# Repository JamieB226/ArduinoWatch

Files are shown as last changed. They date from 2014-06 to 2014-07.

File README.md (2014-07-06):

ArduinoWatch
============

Code for ArduinoWatch<BR>

Android - Android App Project<BR>
Arduino - Code for the Arduino<BR>
Diagrams - Fritzing diagram of the connections in the project<BR>
Libraries - Libraries for the Arduino project (mine and modified from Adafruit)

Required components:<BR>
<BR>
Arduino Pro Mini - 3.3V 8MHz version - <A HREF="http://arduino.cc/en/Main/ArduinoBoardProMini">link</A><BR>
Adafruid Bluefruit LE breakout board (nRF8001 chipset) -  <A HREF="http://www.adafruit.com/products/1697">link</A><BR>
Monochrome 1.3" 128x64 OLED Display (SSD1306 controller) -  <A HREF="http://www.adafruit.com/products/938">link</A><BR>
USB LiIon/LiPoly charger - <A HREF="http://www.adafruit.com/products/259">link</A><BR>
FTDI Basic breakout (to upload code to Arduino - not required in final design) - <A HREF="https://www.sparkfun.com/products/9873">link</A><BR>
400 mAH Lithium Polymer battery - <A HREF="https://www.sparkfun.com/products/10718">link</A><BR>
Vibration Motor - <A HREF="http://www.adafruit.com/products/1201">link</A>

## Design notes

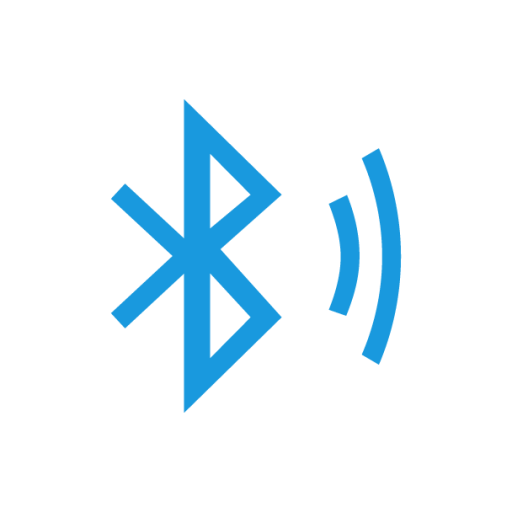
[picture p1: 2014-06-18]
Android/ic_launcher-web.png

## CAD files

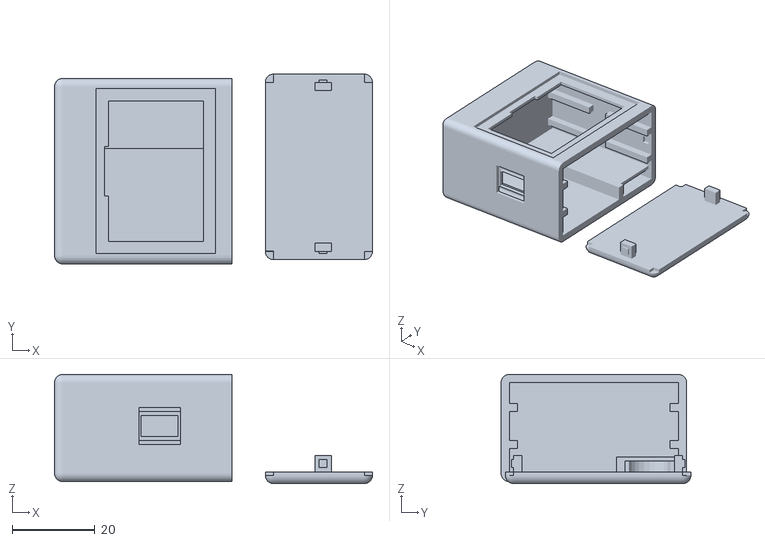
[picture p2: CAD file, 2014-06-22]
Diagrams/ArduinoWatch.stl
77.1 x 46.0 x 26.5

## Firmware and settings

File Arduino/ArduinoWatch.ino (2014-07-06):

#include <SPI.h>
#include "Adafruit_BLE_UART.h"
#include <Wire.h>
#include <avr/pgmspace.h>
#include "Time.h"

#define ADAFRUITBLE_REQ 5
#define ADAFRUITBLE_RDY 2     // This should be an interrupt pin, on Uno thats #2 or #3
#define ADAFRUITBLE_RST 9
Adafruit_BLE_UART BTLEserial = Adafruit_BLE_UART(ADAFRUITBLE_REQ, ADAFRUITBLE_RDY, ADAFRUITBLE_RST);
aci_evt_opcode_t laststatus;

// pin definitions
#define OLED_DATA 11
#define OLED_CLK 13
#define OLED_DC 6
#define OLED_CS 7
#define OLED_RST 8

#define VIBRATION 4
#define BATTSTAT1 A0
#define BATTSTAT2 A1

#include <SSD1306ASCII.h>
#define SSD1306_COLUMNADDR 0x21
#define SSD1306_PAGEADDR   0x22

uint8_t xpos=0,ypos=0;

static unsigned char __attribute__ ((progmem)) GMail_Logo[]={0xFF,0xFF,0x06,0x06,0x0C,0x0C,0x06,0x06,0xFF,0xFF};
static unsigned char __attribute__ ((progmem)) EMail_Logo[]={0xFF,0x83,0x85,0x89,0x91,0x91,0x89,0x85,0x83,0xFF};
static unsigned char __attribute__ ((progmem)) RSS_Logo[]={0xDB,0xDB,0x1B,0xF3,0xEE,0x0E,0xFC,0xF0};
static unsigned char __attribute__ ((progmem)) NestHome_Logo[]={0x00,0x3C,0x7E,0x81,0xE7,0xE7,0xE7,0x81,0x7E,0x3C};
static unsigned char __attribute__ ((progmem)) NestAway_Logo[]={0x00,0x3C,0x7E,0x83,0xED,0xED,0xED,0x83,0x7E,0x3C};
static unsigned char __attribute__ ((progmem)) Charged_Logo[]={0x18,0x38,0x70,0xE0,0x70,0x38,0x1C,0x0E,0x07,0x03};
static unsigned char __attribute__ ((progmem)) Charging_Logo[]={0x00,0x1C,0x3C,0x3F,0xFC,0xFC,0x3F,0x3C,0x1C,0x00};
  
static unsigned char __attribute__ ((progmem)) font[] = {
  0x00, 0x00, 0x00, 0x00, 0x00, // SPACE
  0x00, 0x00, 0x5F, 0x00, 0x00, // !
  0x00, 0x03, 0x00, 0x03, 0x00, // "
  0x14, 0x3E, 0x14, 0x3E, 0x14, // #
  0x24, 0x2A, 0x7F, 0x2A, 0x12, // $
  0x43, 0x33, 0x08, 0x66, 0x61, // %
  0x36, 0x49, 0x55, 0x22, 0x50, // &
  0x00, 0x05, 0x03, 0x00, 0x00, // '
  0x00, 0x1C, 0x22, 0x41, 0x00, // (
  0x00, 0x41, 0x22, 0x1C, 0x00, // )
  0x14, 0x08, 0x3E, 0x08, 0x14, // *
  0x08, 0x08, 0x3E, 0x08, 0x08, // +
  0x00, 0x50, 0x30, 0x00, 0x00, // ,
  0x08, 0x08, 0x08, 0x08, 0x08, // -
  0x00, 0x60, 0x60, 0x00, 0x00, // .
  0x20, 0x10, 0x08, 0x04, 0x02, // /
  0x3E, 0x51, 0x49, 0x45, 0x3E, // 0
  0x00, 0x04, 0x02, 0x7F, 0x00, // 1
  0x42, 0x61, 0x51, 0x49, 0x46, // 2
  0x22, 0x41, 0x49, 0x49, 0x36, // 3
  0x18, 0x14, 0x12, 0x7F, 0x10, // 4
  0x27, 0x45, 0x45, 0x45, 0x39, // 5
  0x3E, 0x49, 0x49, 0x49, 0x32, // 6
  0x01, 0x01, 0x71, 0x09, 0x07, // 7
  0x36, 0x49, 0x49, 0x49, 0x36, // 8
  0x26, 0x49, 0x49, 0x49, 0x3E, // 9
  0x00, 0x36, 0x36, 0x00, 0x00, // :
  0x00, 0x56, 0x36, 0x00, 0x00, // ;
  0x08, 0x14, 0x22, 0x41, 0x00, // <
  0x14, 0x14, 0x14, 0x14, 0x14, // =
  0x00, 0x41, 0x22, 0x14, 0x08, // >
  0x02, 0x01, 0x51, 0x09, 0x06, // ?
  0x3E, 0x41, 0x59, 0x55, 0x5E, // @
  0x7E, 0x09, 0x09, 0x09, 0x7E, // A
  0x7F, 0x49, 0x49, 0x49, 0x36, // B
  0x3E, 0x41, 0x41, 0x41, 0x22, // C
  0x7F, 0x41, 0x41, 0x41, 0x3E, // D
  0x7F, 0x49, 0x49, 0x49, 0x41, // E
  0x7F, 0x09, 0x09, 0x09, 0x01, // F
  0x3E, 0x41, 0x41, 0x49, 0x3A, // G
  0x7F, 0x08, 0x08, 0x08, 0x7F, // H
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
  0x02, 0x04, 0x08, 0x10, 0x20, // backslash
  0x00, 0x00, 0x41, 0x7F, 0x00, // ]
  0x04, 0x02, 0x01, 0x02, 0x04, // ^
  0x40, 0x40, 0x40, 0x40, 0x40, // _
  0x00, 0x01, 0x02, 0x04, 0x00, // `
  0x20, 0x54, 0x54, 0x54, 0x78, // a
  0x7F, 0x44, 0x44, 0x44, 0x38, // b
  0x38, 0x44, 0x44, 0x44, 0x44, // c
  0x38, 0x44, 0x44, 0x44, 0x7F, // d
  0x38, 0x54, 0x54, 0x54, 0x18, // e
  0x04, 0x04, 0x7E, 0x05, 0x05, // f
  0x08, 0x54, 0x54, 0x54, 0x3C, // g
  0x7F, 0x08, 0x04, 0x04, 0x78, // h
  0x00, 0x44, 0x7D, 0x40, 0x00, // i
  0x20, 0x40, 0x44, 0x3D, 0x00, // j
  0x7F, 0x10, 0x28, 0x44, 0x00, // k
  0x00, 0x41, 0x7F, 0x40, 0x00, // l
  0x7C, 0x04, 0x78, 0x04, 0x78, // m
  0x7C, 0x08, 0x04, 0x04, 0x78, // n
  0x38, 0x44, 0x44, 0x44, 0x38, // o
  0x7C, 0x14, 0x14, 0x14, 0x08, // p
  0x08, 0x14, 0x14, 0x14, 0x7C, // q
  0x00, 0x7C, 0x08, 0x04, 0x04, // r
  0x48, 0x54, 0x54, 0x54, 0x20, // s
  0x04, 0x04, 0x3F, 0x44, 0x44, // t
  0x3C, 0x40, 0x40, 0x20, 0x7C, // u
  0x1C, 0x20, 0x40, 0x20, 0x1C, // v
  0x3C, 0x40, 0x30, 0x40, 0x3C, // w
  0x44, 0x28, 0x10, 0x28, 0x44, // x
  0x0C, 0x50, 0x50, 0x50, 0x3C, // y
  0x44, 0x64, 0x54, 0x4C, 0x44, // z
  0x00, 0x08, 0x36, 0x41, 0x41, // {
  0x00, 0x00, 0x7F, 0x00, 0x00, // |
  0x41, 0x41, 0x36, 0x08, 0x00, // }
  0x02, 0x01, 0x02, 0x04, 0x02, // ~
};

boolean blnConnected=false;
boolean blnBTInit=false;
boolean blnDayAdded=false;
boolean blnBTAddrFound=false;
boolean blnBTAddrDisp=false;
boolean blnNotificationUpdate=true;
boolean blnNestHome=true; // Home=true, Away=false
uint8_t intChargeStatus,intOldChargeStatus;
uint8_t currentHour,currentMin,currentSec;
uint8_t intGmail=0,intEmail=0;
uint16_t intRSS=0;
String currentToD;
Time currentTime;
Date currentDate;
uint32_t timer;
uint32_t NotificationStartTime=millis();
aci_evt_opcode_t status;
//int freeRAM=0;

void setup()
{
  Serial.begin(9600);
  Serial.println(F("In init"));
  //Setup up vibration motor
  pinMode(VIBRATION,OUTPUT);
  
  //Setup charging monitor
  // Not connected:  BATTSTAT1 = HI, BATTSTAT2 = HI, intChargeStatus=0
  // Charging:  BATTSTAT1 = L, BATTSTAT2 = HI, intChargeStatus=1
  // Charge Complete:  BATTSTAT1 = HI, BATTSTAT2 = L,intChargeStatus=2
  pinMode(BATTSTAT1,INPUT);
  pinMode(BATTSTAT2,INPUT);
  intChargeStatus=0;
  intOldChargeStatus=0;
  updateChargeStatus();
  
  //Set default Nest to away
  blnNestHome=false;
  
  blnBTInit=false;
  Serial.println(F("Setting up SPI"));
  SPI.begin ();
  SPI.setClockDivider(SPI_CLOCK_DIV8);
  SPI.setDataMode(SPI_MODE0);
  Serial.println(F("Setting up common pins"));
  pinMode(OLED_DATA,OUTPUT);
  pinMode(OLED_CLK,OUTPUT);
  Serial.println(F("Setting up Display Pins"));
  pinMode(OLED_DC,OUTPUT);
  pinMode(OLED_CS,OUTPUT);
  pinMode(OLED_RST,OUTPUT);
  Serial.println(F("Trigger reset of display"));
  digitalWrite(OLED_RST,HIGH);
  delay(1);
  digitalWrite(OLED_RST,LOW);
  delay(10);
  digitalWrite(OLED_RST,HIGH);
  Serial.println(F("Initializing Display"));
  // Init sequence for 128x64 OLED module
  ssd1306_command(SSD1306_DISPLAYOFF);          // 0xAE
  ssd1306_command(SSD1306_SETDISPLAYCLOCKDIV);  // 0xD5
  ssd1306_command(0x80);                        // the suggested ratio 0x80
  ssd1306_command(SSD1306_SETMULTIPLEX);        // 0xA8
  ssd1306_command(0x3F);
  ssd1306_command(SSD1306_SETDISPLAYOFFSET);    // 0xD3
  ssd1306_command(0x0);                         // no offset
  ssd1306_command(SSD1306_SETSTARTLINE | 0x0);  // line #0
  ssd1306_command(SSD1306_CHARGEPUMP);          // 0x8D 
  ssd1306_command(0x14);
  ssd1306_command(SSD1306_MEMORYMODE);          // 0x20
  ssd1306_command(0x02);                        // 0x2 page mode
  ssd1306_command(SSD1306_SEGREMAP | 0x1);
  ssd1306_command(SSD1306_COMSCANDEC);
  ssd1306_command(SSD1306_SETCOMPINS);          // 0xDA
  ssd1306_command(0x12);
  ssd1306_command(SSD1306_SETCONTRAST);         // 0x81
  ssd1306_command(0xCF);
  ssd1306_command(SSD1306_SETPRECHARGE);        // 0xd9
  ssd1306_command(0xF1);
  ssd1306_command(SSD1306_SETVCOMDETECT);       // 0xDB
  ssd1306_command(0x40);
  ssd1306_command(SSD1306_DISPLAYALLON_RESUME); // 0xA4
  ssd1306_command(SSD1306_NORMALDISPLAY);       // 0xA6
  Serial.println(F("Turning on display"));
  ssd1306_command(SSD1306_DISPLAYON);
  
  Serial.println(F("Clearing display"));
  blankDisplay(0);
  setCursor(0,0);
  
  blnBTInit=true;
  Serial.println(F("Initializing BTLE"));
  SPI.setBitOrder(LSBFIRST);
  digitalWrite(ADAFRUITBLE_RST,HIGH);
  delay(30);
  BTLEserial.begin();
  SPI.setBitOrder(MSBFIRST);
  
  blnConnected=false;
  blnDayAdded=false;
  blnBTAddrFound=false;
  blnBTAddrDisp=false;
  currentTime.setTime(12,0,0,0);
  currentHour=currentTime.getHours();
  currentMin=currentTime.getMinutes();
  currentSec=currentTime.getSeconds();
  currentToD="PM";
  currentDate.setDate(2014,1,1);
  
  timer=millis();
  
  writeTime(currentTime.getAMPMHours(),currentTime.getMinutes(),currentTime.getSeconds(),currentToD,true);
  writeDate(currentDate.getDoW(),currentDate.getYear(),currentDate.getMonth(),currentDate.getDay());
  writeNotificationLine(0,0,0,1,intChargeStatus);

  Serial.println(F("Init complete"));
}

void loop()
{ 
  //Update Charge Status
  updateChargeStatus();
  if(intOldChargeStatus != intChargeStatus)
  {
    writeChargeStatus(intChargeStatus);
    intOldChargeStatus = intChargeStatus;
  }
  
  BTLEserial.pollACI();
  status=BTLEserial.getState();

  if (status == ACI_EVT_DEVICE_STARTED) 
  {
    if(status != laststatus)
    {
      Serial.println(F("* Advertising started"));
      writeBlankLine(3);
      setCursor(0,2);
      writeString("Ready...");
    }
    if(BTLEserial.strBTAddr.length()  > 0)
    {
      if(blnBTAddrDisp == false && blnBTAddrFound==true)
      {
        setCursor(50,2);
        Serial.println(F("Read the following from strBTAddr"));
        Serial.println(BTLEserial.strBTAddr);
        writeString(BTLEserial.strBTAddr);
        blnBTAddrDisp=true;
      }
      blnBTAddrFound=true;
    }
    blnConnected=false;
  }
  if (status == ACI_EVT_CONNECTED) 
  {
    if(status != laststatus)
    {
      Serial.println(F("* Connected!"));
      if (blnConnected == false)
      {
        writeBlankLine(2);
        writeBlankLine(3);
        blnBTAddrDisp=false;
        setCursor(0,3);
        //writeString("Connected.");
      }
    }
    blnConnected = true;
    String strOutput="";
    setCursor(0,3);
    // OK while we still have something to read, get a character and print it out
    while (BTLEserial.available() > 0) 
    {
      if((strOutput.length()!=0 && BTLEserial.peek() != '$') || (strOutput.length()==0 && BTLEserial.peek() == '$'))
      {
        strOutput.concat((char)BTLEserial.read());
      }
      else
      { 
        processBTInput(strOutput);
        strOutput="";
      }
    }
    if(strOutput.length() != 0)
    {
      processBTInput(strOutput);
    }
  }
  if (status == ACI_EVT_DISCONNECTED || status == ACI_EVT_INVALID || status == ACI_EVT_HW_ERROR || status == ACI_EVT_PIPE_ERROR) 
  {
      if(status != laststatus)
      {
        Serial.println(F("* Disconnected or advertising timed out"));
        writeBlankLine(3);
        setCursor(0,2);
        writeString("Ready...");
        blnConnected=false;
      }
      if(BTLEserial.strBTAddr.length()  > 0)
      {
        if(blnBTAddrDisp == false && blnBTAddrFound==true)
        {
          setCursor(50,2);
          Serial.println(F("Read the following from strBTAddr"));
          Serial.println(BTLEserial.strBTAddr);
          writeString(BTLEserial.strBTAddr);
          blnBTAddrDisp=true;
        }
        blnBTAddrFound=true;
      }
  }
  // OK set the last status change to this one
  laststatus = status;
    
  //Do Time computations
  if((millis()-timer) > 0)
  {
    uint32_t temp_timer;
    
    temp_timer=millis();
    currentTime.addMilliseconds(temp_timer-timer);
    timer=temp_timer;
  }
  else
  {
    uint32_t temp_timer;
    
    temp_timer=millis();
    currentTime.addMilliseconds((2^32)-timer+temp_timer);
    timer=temp_timer;
  }
  
  //Get correct AM/PM value
  if(currentTime.getHours() > 12)
  {
    currentToD="PM";
  }
  else
  {
    currentToD="AM";
  }
  
  //Print new Time
  if(currentHour==99)
  {
    writeTime(currentTime.getAMPMHours(),currentTime.getMinutes(),currentTime.getSeconds(),currentToD,true);
    writeDate(currentDate.getDoW(),currentDate.getYear(),currentDate.getMonth(),currentDate.getDay());
  }
  else
  {
//    if(timer>millis())
//    {
//      //We just wrapped over
//      //Clear notification and update time in case we were in the middle of a notification.
//      NotificationStartTime=0;
//      writeTime(currentTime.getAMPMHours(),currentTime.getMinutes(),currentTime.getSeconds(),currentToD,true);
//    }
//    else
//    {
//      if(NotificationStartTime+5000 > millis())
//      {
//        //Skip time update because notification is being displayed
//      }
//      else
//      {
        writeTime(currentTime.getAMPMHours(),currentTime.getMinutes(),currentTime.getSeconds(),currentToD,false);
//      }
//
//    }
  }  
  
  // Update Date if required (time is midnight and we haven't already added a day)
  if(currentTime.getHours()==0 && currentTime.getMinutes()==0 && blnDayAdded==false)
  {
    currentDate.addDay();
    writeDate(currentDate.getDoW(),currentDate.getYear(),currentDate.getMonth(),currentDate.getDay());
    blnDayAdded=true;
  }
  
  // Reset day update flag at 12:01:00 AM each day
  if(currentTime.getHours()==0 && currentTime.getMinutes()==1 && blnDayAdded==true)
  {
    blnDayAdded=false;
  }

  if(blnNotificationUpdate == true)
  {
    writeNotificationLine(intGmail,intEmail,intRSS,blnNestHome,intChargeStatus);
  }
}

void updateChargeStatus()
{
  // Not connected:  BATTSTAT1 = HI, BATTSTAT2 = HI, intChargeStatus=0
  // Charging:  BATTSTAT1 = L, BATTSTAT2 = HI, intChargeStatus=1
  // Charge Complete:  BATTSTAT1 = HI, BATTSTAT2 = L,intChargeStatus=2
  
  if(digitalRead(BATTSTAT1) == HIGH && digitalRead(BATTSTAT2) == HIGH)
  {
    intChargeStatus=0;
  }
  else if (digitalRead(BATTSTAT1) == LOW && digitalRead(BATTSTAT2) == HIGH)
  {
    intChargeStatus=1;
  }
  else if (digitalRead(BATTSTAT1) == HIGH && digitalRead(BATTSTAT2) == LOW)
  {
    intChargeStatus=2;
  }
  else
  {
    intChargeStatus=0;
  }
}

void processBTInput(String s)
{
//  if(blnDebug == true)
//  {
//    writeBlankLine(2);
//    setCursor(0,2);
//    writeString(s);
//  }
  
  if(s.startsWith("$tm") == true)
  {
    processIncomingTime(s);
  }
  if(s.startsWith("$rs") == true)
  {
    void(* resetFunc) (void) = 0;//declare reset function at address 0
    resetFunc();
  }
  if(s.startsWith("$nf") == true)
  {
    processIncomingNotificationUpdate(s);
  }
  if(s.startsWith("$em") == true)
  {
    processIncomingEmail(s);
  }
  if(s.startsWith("$cl") == true)
  {
    processIncomingCall(s);
  }
//  if(s.startsWith("$g1") == true)
//  {
//    NotificationStartTime=millis();
//    processGeneralNotification(s,1);
//  }
//  if(s.startsWith("$g2") == true)
//  {
//    processGeneralNotification(s,2);
//  }
//  if(s.startsWith("$g3") == true)
//  {
//    processGeneralNotification(s,3);
//  }
//  if(s.startsWith("$db") == true)
//  {
//    blnDebug=!blnDebug;
//    writeBlankLine(2);
//  }
}

//void processGeneralNotification(String s,int line)
//{
//  writeBlankLine(line+2);
//  setCursor(0,line+2);
//  writeString(s.substring(3));
//  if(line == 3)
//  {
//    vibrate(1);
//    delay(3000);
//    writeBlankLine(3);
//    writeBlankLine(4);
//    writeBlankLine(5);
//    currentHour=99;
//  }
//}

void processIncomingTime(String s)
{
  blnDayAdded=false;
  
  currentTime.setTime((s.substring(11,13)).toInt(),(s.substring(13,15)).toInt(),(s.substring(15,17)).toInt(),0);
  currentDate.setDate((s.substring(3,7)).toInt(),(s.substring(7,9)).toInt(),(s.substring(9,11)).toInt());
  
//  writeTime(currentTime.getAMPMHours(),currentTime.getMinutes(),currentTime.getSeconds(),currentToD,true);
//  writeDate(currentDate.getDoW(),currentDate.getYear(),currentDate.getMonth(),currentDate.getDay());
  currentHour=99;
}

void processIncomingNotificationUpdate(String s)
{
  uint8_t intStart,intEnd,intNest;
  
  intStart=3;
  intEnd=s.indexOf(',');
  intGmail=s.substring(intStart,intEnd).toInt();
  intStart=intEnd+1;
  intEnd=s.indexOf(',',intStart);
  intEmail=s.substring(intStart,intEnd).toInt();
  intStart=intEnd+1;
  intEnd=s.indexOf(',',intStart);
  intRSS=s.substring(intStart,intEnd).toInt();
  intStart=intEnd+1;
  intEnd=s.length();
  intNest=(s.substring(intStart,intEnd).toInt());
  
  if(intNest == 0)
  {
    blnNestHome=false;
  }
  else
  {
    blnNestHome=true;
  }
  
  blnNotificationUpdate=true;
}

void processIncomingEmail(String s)
{
  writeBlankLine(3);
  writeBlankLine(4);
  writeBlankLine(5);
  setCursor(0,3);
  writeString("Email from:");
  setCursor(0,4);
  writeBigString(s.substring(3));
  vibrate(1);
  delay(500);
  vibrate(1);
  delay(3000);
  writeBlankLine(3);
  writeBlankLine(4);
  writeBlankLine(5);
  currentHour=99;
}

void processIncomingCall(String s)
{
    writeBlankLine(3);
    writeBlankLine(4);
    writeBlankLine(5);
    setCursor(0,3);
    writeString("Call from:");
    setCursor(0,4);
    writeBigString(s.substring(3));
    vibrate(2);
    delay(3000);
    writeBlankLine(3);
    writeBlankLine(4);
    writeBlankLine(5);
    currentHour=99;
}

void writeNotificationLine(uint8_t numGmail,uint8_t numEmail, uint16_t numRSS,boolean nestHome,uint8_t chargeStatus)
{
  writeBlankLine(0);
  writeLogo(GMail_Logo,10,0,0);
  setCursor(13,0);
  writeString(String(numGmail));
  writeLogo(EMail_Logo,10,32,0);
  setCursor(45,0);
  writeString(String(numEmail));
  writeLogo(RSS_Logo,8,64,0);
  setCursor(74,0);
  writeString(String(numRSS));
  if(nestHome == true)
  {
    writeLogo(NestHome_Logo,10,95,0);
  }
  else
  {
    writeLogo(NestAway_Logo,10,95,0);
  }
  writeChargeStatus(chargeStatus);
  
  blnNotificationUpdate=false;
}

void writeChargeStatus(uint8_t chargeStatus)
{
  if(chargeStatus == 1)
  {
    writeLogo(Charging_Logo,10,117,0);
  }
  else if (chargeStatus == 2)
  {
    writeLogo(Charged_Logo,10,117,0);
  }
}

void ssd1306_command(uint8_t c)
{
  while(digitalRead(ADAFRUITBLE_RDY) == LOW && blnBTInit==true)
  {
    delay(10);
  }
  //Disable interrupts to make sure BT doesn't send data during display writes
  cli();

  digitalWrite(OLED_CS, HIGH);
  digitalWrite(OLED_DC, LOW);
  digitalWrite(OLED_CS, LOW);
  SPI.transfer(c);
  digitalWrite(OLED_CS, HIGH);
  
  //Reenable interrupts
  sei();
}

void ssd1306_data(uint8_t c) 
{
  while(digitalRead(ADAFRUITBLE_RDY) == LOW & blnBTInit==true)
  {
    delay(10);
   }
   
  //Disable interrupts to make sure BT doesn't send data during display writes
  cli();
  
  digitalWrite(OLED_CS, HIGH);
  digitalWrite(OLED_DC, HIGH);
  digitalWrite(OLED_CS, LOW);
  SPI.transfer(c);
  digitalWrite(OLED_CS, HIGH);
  
  //Reenable interrupts
  sei();
}

void blankDisplay(uint8_t color)
{
  uint16_t i,j;
  byte temp;
  
  if (color==0)
  {
    temp=(uint8_t)0;
  }
  else
  {
    temp=(uint8_t)255;
  }
  
  //Configure Display for Horizontal Addressing
  ssd1306_command(0x20);
  ssd1306_command(0b00100000);
  
  //Set cursor to 0,0
  ssd1306_command(0x21);
  ssd1306_command(0);
  ssd1306_command(127);
  ssd1306_command(SSD1306_SETLOWCOLUMN | (0 & 0XF));
  ssd1306_command(SSD1306_SETHIGHCOLUMN | (0 >> 4));
  ssd1306_command(SSD1306_SETSTARTPAGE | 0);
  
  //Send 1024 bytes to display
  for (i=0;i<1024;i++)
  {
    ssd1306_data(temp);
  }
  
  //Set display back to Page Addressing Mode
  ssd1306_command(0x20);
  ssd1306_command(0b10);
}

void writeDisplay(byte c, uint8_t page_x, uint8_t page_y)
{ 
  if ((page_x < 128) && (page_y < 8))
  {
    //Configure display location
    ssd1306_command(SSD1306_SETLOWCOLUMN | (page_x & 0XF));
    ssd1306_command(SSD1306_SETHIGHCOLUMN | (page_x >> 4));
    ssd1306_command(SSD1306_SETSTARTPAGE | page_y);
    
    //Send byte to display
    ssd1306_data(c);
  }
}

void writeDate(uint8_t dow,uint16_t year,uint8_t month,uint8_t day)
{
  String temp="";
  
  switch(dow)
  {
    case 0:
      temp.concat("SUN ");
      temp=temp+year+" / "+month+" / "+day;
      break;
    case 1:
      temp.concat("MON ");
      temp=temp+year+" / "+month+" / "+day;
      break;
    case 2:
      temp.concat("TUE ");
      temp=temp+year+" / "+month+" / "+day;
      break;
    case 3:
      temp.concat("WED ");
      temp=temp+year+" / "+month+" / "+day;
      break;
    case 4:
      temp.concat("THU ");
      temp=temp+year+" / "+month+" / "+day;
      break;
    case 5:
      temp.concat("FRI ");
      temp=temp+year+" / "+month+" / "+day;
      break;
    case 6:
      temp.concat("SAT ");
      temp=temp+year+" / "+month+" / "+day;
      break;
  }
  
  writeBlankLine(7);
  writeString(temp,9,7);
}

void writeTime(uint8_t hour,uint8_t minute,uint8_t second,String ToD,boolean fullRefresh)
{
  String strHour,strMin,strSec;
  
  if(fullRefresh == true)
  {
    currentHour=99;
    currentMin=99;
    currentSec=99;
    writeBlankLine(4);
    writeBlankLine(5);
  }
  
  if(hour != currentHour)
  {
    currentHour=hour;
    strHour=String(hour);
    Serial.print(F("strHour="));
    Serial.println(strHour);
    if(strHour.length() < 2)
    {
      strHour=' '+strHour;
    }
    setCursor(5,4);
    writeBigString(strHour);
  }
  setCursor(30,4);
  writeBigChar(':');
  if(minute != currentMin)
  {
    currentMin=minute;
    strMin=String(minute);
    Serial.print(F("strMin="));
    Serial.println(strMin);
    if(strMin.length() <2)
    {
      strMin='0'+strMin;
    }
    setCursor(41,4);
    writeBigString(strMin);
  }
  setCursor(63,4);
  writeBigChar(':');
  if(second != currentSec)
  {
    currentSec=second;
    strSec=String(second);
    if(strSec.length() <2)
    {
      strSec='0'+strSec;
    }
    setCursor(74,4);
    writeBigString(strSec);
  }
  setCursor(107,4);
  writeString(ToD);
}

void writeString(String s)
{
  uint8_t i=0;
  
  while (i<s.length())
  {
    writeChar(s.charAt(i));
    i++;
  } 
}

void writeBigString(String s)
{
  uint8_t i=0;
  
  while (i<s.length())
  {
    writeBigChar(s.charAt(i));
    i++;
  } 
}

void writeBlankLine(uint8_t y)
{
  uint8_t i;
  byte temp=0x00;
  
  for(i=0;i<128;i++)
  {
    writeDisplay(temp,i,y);
  }
}

void writeString(String s,uint8_t x,uint8_t y)
{
  uint8_t i=0;
  
  setCursor(x,y);
  while (i<s.length())
  {
    writeChar(s.charAt(i));
    i++;
  } 
}

void writeLogo(unsigned char logo[],uint8_t width,uint8_t x,uint8_t y)
{
  uint8_t i=0;
  
  setCursor(x,y);
  while(i<width)
  {
    writeDisplay(pgm_read_byte(&(logo[i])),x+i,y);
    i++;
  }
}
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

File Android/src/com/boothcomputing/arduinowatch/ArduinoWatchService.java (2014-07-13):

package com.boothcomputing.arduinowatch;

import java.io.BufferedReader;
import java.io.IOException;
import java.io.InputStream;
import java.io.InputStreamReader;
import java.io.OutputStream;
import java.io.UnsupportedEncodingException;
import java.nio.ByteBuffer;
import java.nio.ByteOrder;
import java.text.SimpleDateFormat;
import java.util.ArrayList;
import java.util.Calendar;
import java.util.Date;
import java.util.List;
import java.util.Set;
import java.util.TimeZone;
import java.util.Timer;
import java.util.TimerTask;
import java.util.UUID;

import org.apache.http.HttpEntity;
import org.apache.http.HttpResponse;
import org.apache.http.client.methods.HttpPost;
import org.apache.http.entity.StringEntity;
import org.apache.http.impl.client.DefaultHttpClient;
import org.apache.http.params.BasicHttpParams;
import org.json.JSONException;
import org.json.JSONObject;

import com.firebase.client.DataSnapshot;
import com.firebase.client.Firebase;
import com.firebase.client.FirebaseError;
import com.firebase.client.ValueEventListener;

import android.accounts.Account;
import android.accounts.AccountManager;
import android.accounts.AccountManagerCallback;
import android.accounts.AccountManagerFuture;
import android.accounts.AuthenticatorException;
import android.accounts.OperationCanceledException;
import android.app.Service;
import android.bluetooth.BluetoothAdapter;
import android.bluetooth.BluetoothAdapter.LeScanCallback;
import android.bluetooth.BluetoothDevice;
import android.bluetooth.BluetoothGatt;
import android.bluetooth.BluetoothGattCallback;
import android.bluetooth.BluetoothGattCharacteristic;
import android.bluetooth.BluetoothGattDescriptor;
import android.bluetooth.BluetoothSocket;
import android.content.Context;
import android.content.Intent;
import android.content.SharedPreferences;
import android.database.Cursor;
import android.os.Handler;
import android.os.IBinder;
import android.os.ParcelUuid;
import android.preference.PreferenceManager;
import android.util.Log;
import android.widget.EditText;

public class ArduinoWatchService extends Service
{
	public static String strRSSFeedURL;
	public static String strRSSFeedUserName;
	public static String strRSSFeedPassword;
	public static String strNestUserName;
	public static String strNestPIN;
	public static String strAOLUserName;
	public static String strAOLPassword;
	public static String strWatchBTID;
	public static String strNestCode;
	public static int intGmailMessages;
	public static int intIMAPMessages;
	public static int intRSSUnread;
	public static int intNestStatus; //Home=0,Away=1
	private static Calendar dteNestTokenExpires=null;
	byte[] watchBuffer = new byte[32];
	byte[] outBuffer = new byte[32];
	private static boolean blnSync;
	public static long TimeUpdateInterval = 1800000;
	private static long ThrottleDelay = 30000;
	private static Firebase nestapi=null;
	private static String strNestAccessToken="";

	// UUIDs for UAT service and associated characteristics.
	public static UUID UART_UUID = UUID
			.fromString("6E400001-B5A3-F393-E0A9-E50E24DCCA9E");
	public static UUID TX_UUID = UUID
			.fromString("6E400002-B5A3-F393-E0A9-E50E24DCCA9E");
	public static UUID RX_UUID = UUID
			.fromString("6E400003-B5A3-F393-E0A9-E50E24DCCA9E");
	// UUID for the BTLE client characteristic which is necessary for
	// notifications.
	public static UUID CLIENT_UUID = UUID
			.fromString("00002902-0000-1000-8000-00805f9b34fb");
	
	private static String NestClientID="9ebcdba4-7e33-40c7-a766-d1e759b75eea";
	private static String NestClientSecret="5KtcNLgrrcu5dTPkGXaujXRZI";

	// BTLE state
	private BluetoothAdapter adapter;
	private BluetoothGatt gatt;
	private BluetoothGattCharacteristic tx;
	private BluetoothGattCharacteristic rx;

	final Handler timerHandler = new Handler();
	Runnable timerRunnable = new Runnable()
	{

		@Override public void run()
		{

			if (tx != null)
			{
				sendTimeUpdate();
				sendNotificationUpdate();
			}

			timerHandler.postDelayed(this, TimeUpdateInterval);
		}
	};

	public ArduinoWatchService()
	{
		super();

		System.out.println("Service:  Created Service");
		// TODO Auto-generated constructor stub
	}

	protected void onHandleIntent(Intent intent)
	{
		System.out.println("Service:  Processing intent");

		switch (intent.getAction())
		{
		case "StartSync":
			System.out.println("Service:  StartSync");
			blnSync = true;
			break;
		case "ReadSettings":
			System.out.println("Service: ReadSettings");
			readSettings();
			break;
		case "StopSync":
			System.out.println("Service:  StopSync");
			blnSync = false;
			break;
		default:
			System.out.println("Service:  Received unknown Intent Action:"
					+ intent.getAction());
			break;
		}
	}

	public void main(String[] args)
	{

	}

	private void sendTimeUpdate()
	{
		Calendar cal = Calendar.getInstance();
		TimeZone tz = cal.getTimeZone();

		/* date formatter in local timezone */
		SimpleDateFormat sdf = new SimpleDateFormat("yyyyMMddHHmmss");
		sdf.setTimeZone(tz);

		/* Generate time string to send to watch */
		String localTime = "$tm" + sdf.format(new Date());

		try
		{
			sendToWatch(localTime);
		}
		catch (IOException e)
		{
			System.out.println("Connection to watch broken.  Command not sent:"
					+ localTime);
		}
	}

	@SuppressWarnings("deprecation") private void readSettings()
	{
		SharedPreferences settings = getBaseContext().getSharedPreferences(
				"ArduinoWatch", Context.MODE_PRIVATE);
		strRSSFeedURL = settings.getString("RSSFeedURL", "");
		strRSSFeedUserName = settings.getString("RSSFeedUserName", "");
		strRSSFeedPassword = settings.getString("RSSFeedPassword", "");
		strNestPIN = settings.getString("NestPIN", "");
		strAOLUserName = settings.getString("AOLUserName", "");
		strAOLPassword = settings.getString("AOLPassword", "");
		strWatchBTID = settings.getString("WatchBTID", "");
		strNestAccessToken = settings.getString("NestAccessToken", "");
		dteNestTokenExpires = Calendar.getInstance();
		dteNestTokenExpires.setTimeInMillis(settings.getLong("NestAccessTokenExpires", 0));
	}

	private void initWatchConnection() throws IOException
	{
		adapter = BluetoothAdapter.getDefaultAdapter();
		System.out.println("Service:  Scanning for devices...");
		if (adapter != null)
		{
			System.out.println("Service:  Got Default Adapter");
			if (adapter.isEnabled())
			{
				System.out.println("Service:  Bluetooth is Enabled");
				if (BluetoothAdapter.checkBluetoothAddress(strWatchBTID) == true)
				{
					System.out.println("Service:  Watch Bluetooth Address is valid.");
					adapter.startLeScan(scanCallback);
				}
				else
				{
					Log.e("error",
							"Service:  Watch Bluetooth Address is invalid.");
				}
			}
			else
			{
				Log.e("error", "Service:  Bluetooth is disabled.");
			}
		}
	}
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

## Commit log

2014-06-22 Added design for 3D printed case.
    [ArduinoWatch.stl]
2014-06-22 Added timer and communication code.
2014-06-23 Back out security settings
    Too little RAM to store the required data and still have the device
    function. Added handlers for errors to force disconnect so the master
    can reconnect.
    [ArduinoWatch.ino]
2014-06-24 Add BT Address code and Vibration motor
    [ArduinoWatch.fzz]
2014-06-24 Android App updates
    *Switch to Service from IntentService for persistent Service
    *Create thread for Time and notification updates
    *Add error checking for null objects
    *Add Debug code for BT debugging
    [ArduinoWatchService.java]
2014-06-24 Convert BT code to BTLE
    BT code did not work because the watch uses BTLE which is a different
    protocol. Rewrite of connection code in progress.
    [ArduinoWatchService.java]
2014-06-24 Correct BT Address display issue
    BT Address would only display before the initial connection.
    Subsequent connections would only show “Ready…”
    [ArduinoWatch.ino]
2014-06-24 Correct issue with Date display
    Correct issue with Date not being refreshed with time update from Phone.
    [ArduinoWatch.ino]
2014-07-06 Added battery monitoring connections
    Connect A0 and A1 to battery status connections on charger. Update
    Arduino code to report battery status on the display.
    [ArduinoWatch.fzz]
2014-07-06 Add TTRSS support to Android App
    Replace RSS feed with TTRSS connection. Added querying TTRSS for
    unread counts.
    [ArduinoWatchService.java]
